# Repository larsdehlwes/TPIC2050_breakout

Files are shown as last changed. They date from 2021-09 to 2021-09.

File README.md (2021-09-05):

# TPIC2050_breakout
Provisory breakout board for the [TPIC2050](https://www.ti.com/product/TPIC2050), a 3-beam laser diode driver and 9-channel motor driver, for DVD and Blu-Ray drives. The circuit follows too good part the Typical Application circuit from [Section 9.2](https://www.ti.com/document-viewer/TPIC2050/datasheet/application_and_implementation#SLIS1675680) of the Datasheet, with the exception that P5V12L (the power-supply for the load driver) is hard-connected to P5V (the power-supply for the 5V driver such as tilt/track/focus).
<p float="left">


</p>

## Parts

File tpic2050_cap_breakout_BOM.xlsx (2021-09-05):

Comment | Designator | Footprint | JLCPCB Part #（optional）
10uF | C1,C4,C9 | C_0805_2012Metric | C15850
100nF | C2,C3,C5,C6,C7,C8,C10 | C_0402_1005Metric | C1525

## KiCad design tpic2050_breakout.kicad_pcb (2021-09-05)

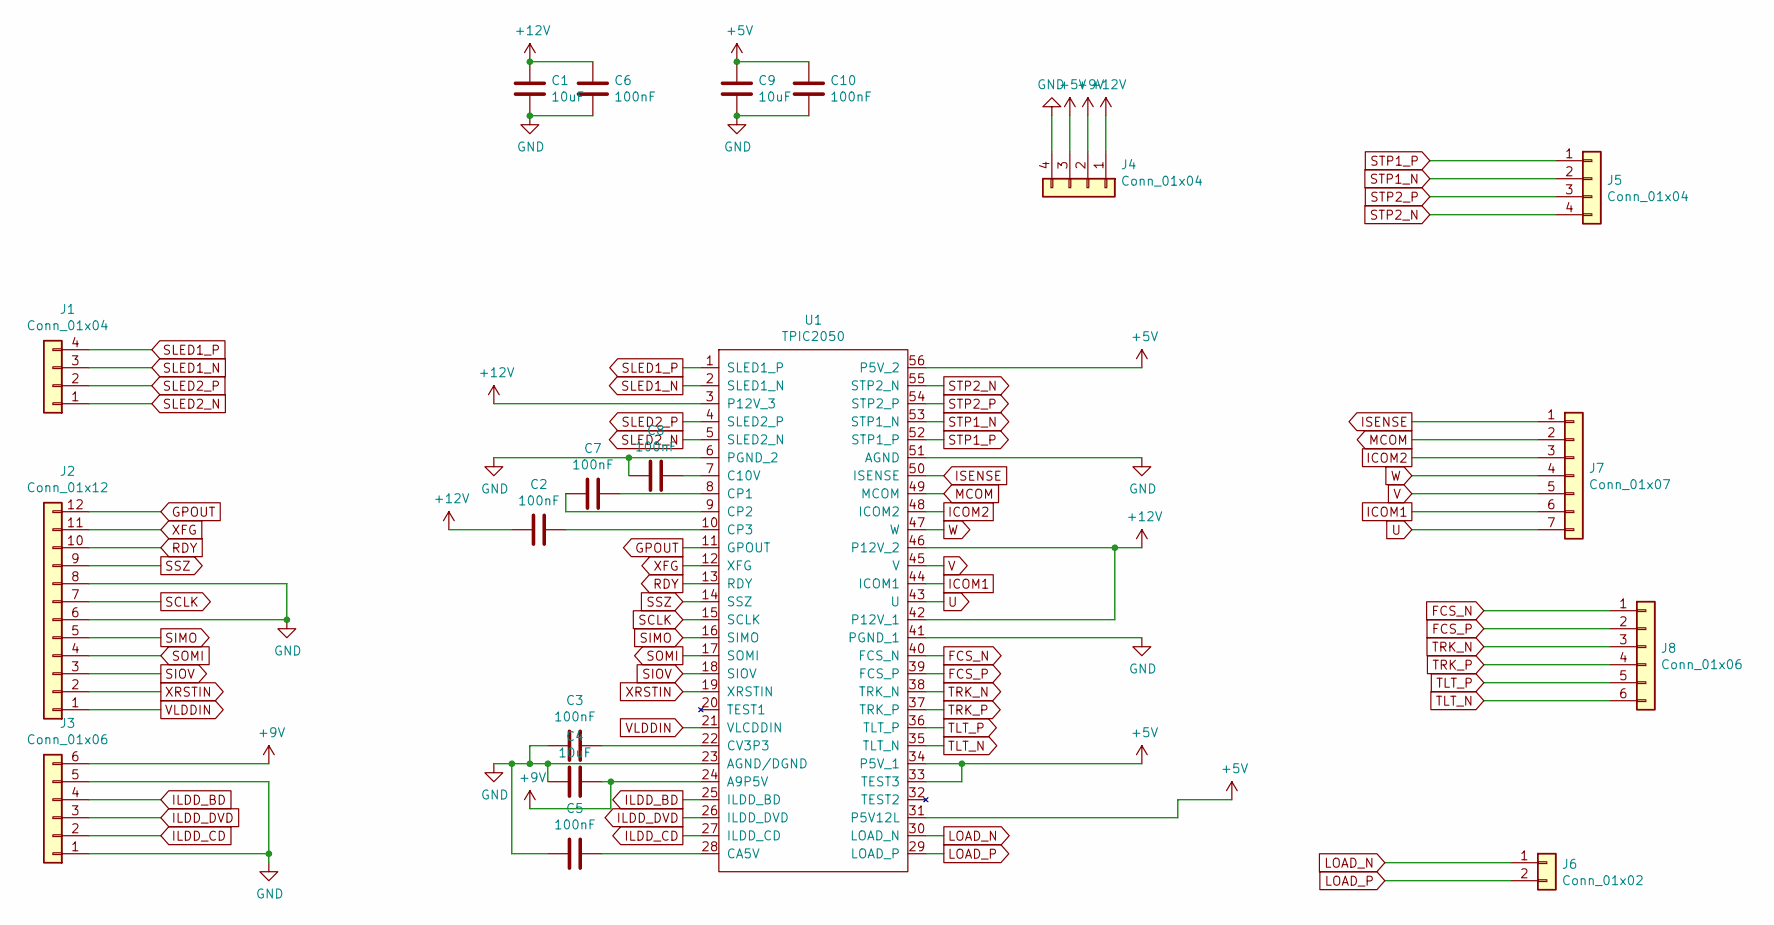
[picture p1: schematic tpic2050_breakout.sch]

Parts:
C1, C4, C9: 10uF; C_0805_2012Metric
C2, C3, C5, C6, C7, C8, C10: 100nF; C_0402_1005Metric
J1, J4, J5: Conn_01x04; PinHeader_1x04_P2.54mm_Vertical
J2: Conn_01x12; PinHeader_1x12_P2.54mm_Vertical
J3, J8: Conn_01x06; PinHeader_1x06_P2.54mm_Vertical
J6: Conn_01x02; PinHeader_1x02_P2.54mm_Vertical
J7: Conn_01x07; PinHeader_1x07_P2.54mm_Vertical
U1: TPIC2050; TSSOP-56_6.1x14mm_P0.5mm

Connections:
+5V: C9.1, C10.1, J4.3, U1.31 (P5V12L), U1.33 (TEST3), U1.34 (P5V_1), U1.56 (P5V_2)
+9V: C4.1, J3.6, J4.2, U1.24 (A9P5V)
+12V: C1.1, C2.2, C6.1, J4.1, U1.3 (P12V_3), U1.42 (P12V_1), U1.46 (P12V_2)
FCS_N: J8.1, U1.40 (FCS_N)
FCS_P: J8.2, U1.39 (FCS_P)
GND: C1.2, C3.2, C4.2, C5.2, C6.2, C8.2, C9.2, C10.2, J2.6, J2.8, J3.1, J3.5, J4.4, U1.6 (PGND_2), U1.23 (AGND/DGND), U1.41 (PGND_1), U1.51 (AGND)
GPOUT: J2.12, U1.11 (GPOUT)
ICOM1: J7.6, U1.44 (ICOM1)
ICOM2: J7.3, U1.48 (ICOM2)
ILDD_BD: J3.4, U1.25 (ILDD_BD)
ILDD_CD: J3.2, U1.27 (ILDD_CD)
ILDD_DVD: J3.3, U1.26 (ILDD_DVD)
ISENSE: J7.1, U1.50 (ISENSE)
LOAD_N: J6.1, U1.30 (LOAD_N)
LOAD_P: J6.2, U1.29 (LOAD_P)
MCOM: J7.2, U1.49 (MCOM)
unnamed: C2.1, U1.10 (CP3)
unnamed: C3.1, U1.22 (CV3P3)
unnamed: C5.1, U1.28 (CA5V)
unnamed: C7.1, U1.8 (CP1)
unnamed: C7.2, U1.9 (CP2)
unnamed: C8.1, U1.7 (C10V)
RDY: J2.10, U1.13 (RDY)
SCLK: J2.7, U1.15 (SCLK)
SIMO: J2.5, U1.16 (SIMO)
SIOV: J2.3, U1.18 (SIOV)
SLED1_N: J1.3, U1.2 (SLED1_N)
SLED1_P: J1.4, U1.1 (SLED1_P)
SLED2_N: J1.1, U1.5 (SLED2_N)
SLED2_P: J1.2, U1.4 (SLED2_P)
SOMI: J2.4, U1.17 (SOMI)
SSZ: J2.9, U1.14 (SSZ)
STP1_N: J5.2, U1.53 (STP1_N)
STP1_P: J5.1, U1.52 (STP1_P)
STP2_N: J5.4, U1.55 (STP2_N)
STP2_P: J5.3, U1.54 (STP2_P)
TLT_N: J8.6, U1.35 (TLT_N)
TLT_P: J8.5, U1.36 (TLT_P)
TRK_N: J8.3, U1.38 (TRK_N)
TRK_P: J8.4, U1.37 (TRK_P)
U: J7.7, U1.43 (U)
V: J7.5, U1.45 (V)
VLDDIN: J2.1, U1.21 (VLCDDIN)
W: J7.4, U1.47 (W)
XFG: J2.11, U1.12 (XFG)
XRSTIN: J2.2, U1.19 (XRSTIN)

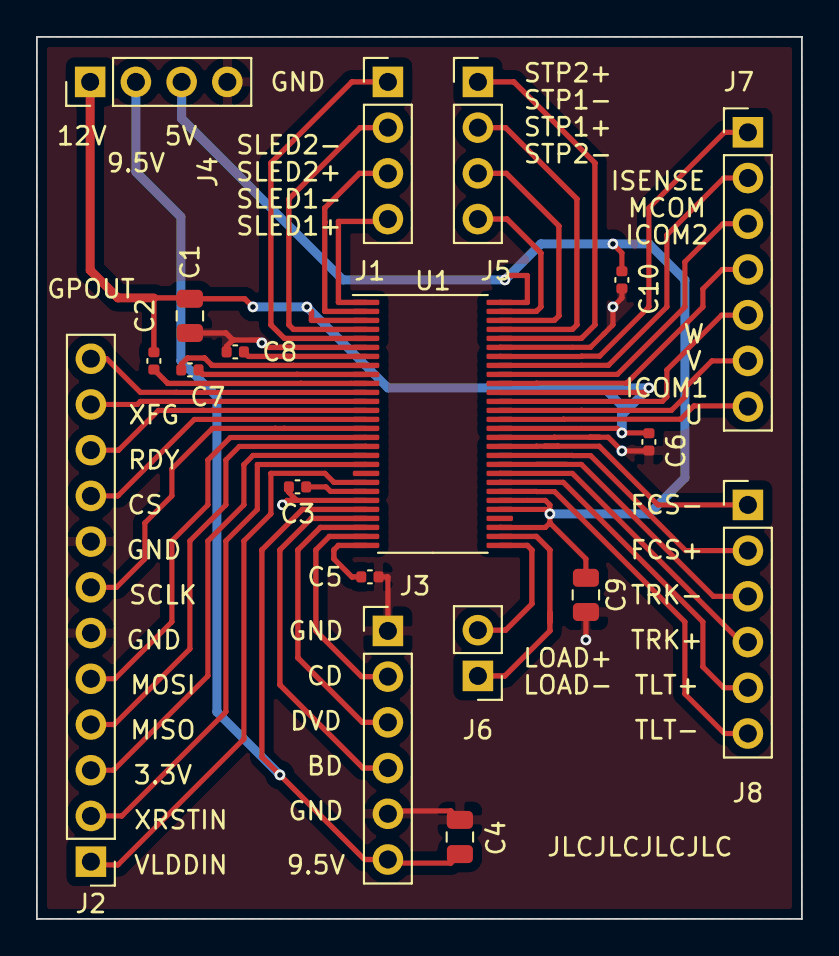
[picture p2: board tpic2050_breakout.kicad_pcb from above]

Board: 2 copper layers, 42.5 x 49.0 mm, 19 parts (0 on the bottom side), 46 nets.
